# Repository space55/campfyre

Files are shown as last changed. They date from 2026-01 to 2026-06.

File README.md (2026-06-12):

# Campfyre

Campfyre is a rugged, battery-powered network‑in‑a‑box designed to keep you online when primary internet access fails. It can run off‑grid with Starlink, provide Ethernet, run a Raspberry Pi, and charge from a vehicle's 12V system. It's compact, durable, and built for travel and off‑grid use.

## Website

Visit the project website at **https://campfyre.org**.

## What Campfyre includes

- Starlink Mini for internet access and routing
- Ethernet switch for local connectivity
- Shared power bus (VBUS) feeding the switch, Starlink, and Raspberry Pi
- Power path controller that prioritizes external power while charging the battery
- 12V regulation with a secondary 5V supply for the Raspberry Pi
- Waterproof, radio‑transparent case for durability and signal quality

## Contributing

We welcome contributions. Please read the guidelines in [CONTRIBUTING.md](CONTRIBUTING.md), which include:

- Submitting changes via GitHub pull requests
- Following the project's community guidelines

For content edits, see the content guide in [site/README.md](site/README.md).

## License

See [LICENSE](LICENSE).

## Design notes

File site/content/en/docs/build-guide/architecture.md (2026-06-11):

---
title: Architecture
description: >
  See how Campfyre is put together.
weight: 3
---

Campfyre is designed around a few key subsystems. Green arrows in the diagrams
are for Ethernet, and red arrows are for power.

## Network

The network of Campfyre is designed to be centralized around a ruggedized
network switch, where a Starlink Mini, a Raspberry Pi, and the output jack are
all connected.

Network diagram for Campfyre

Starlink creates a WiFi hotspot, and connects via Ethernet to the network
switch. The switch then connects to the Raspberry Pi and the water-resistant
external ethernet jack.

## Power

Campfyre receives its power from an internal battery and an external 12V supply.

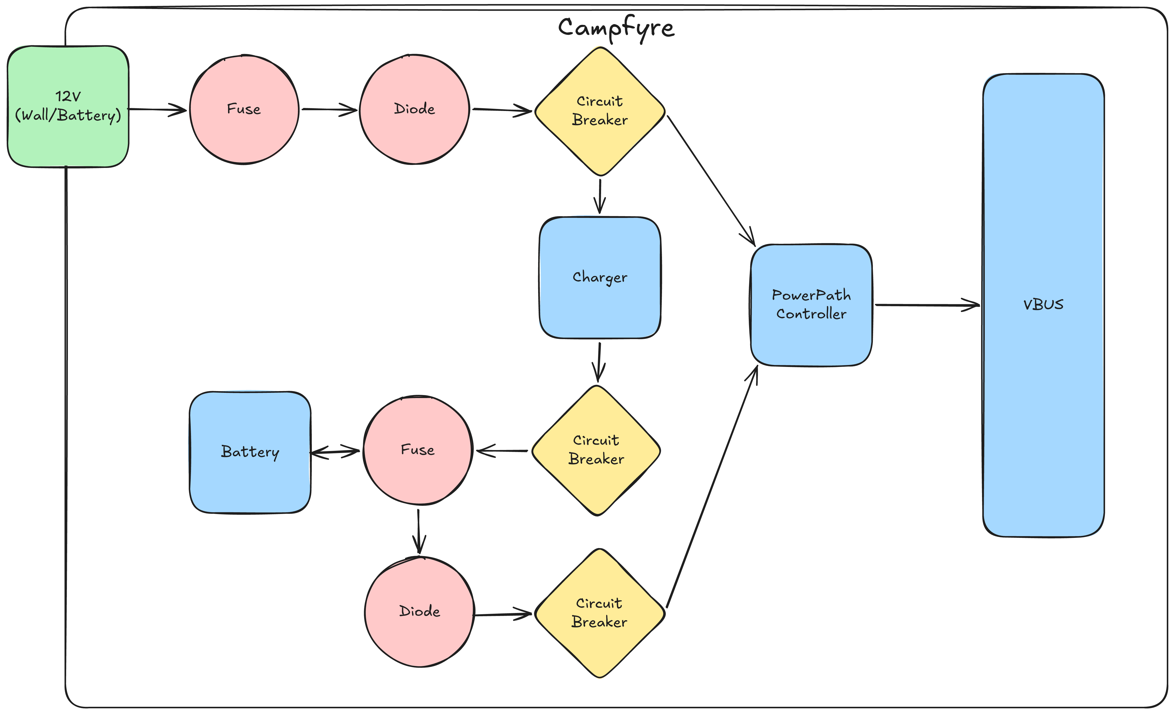
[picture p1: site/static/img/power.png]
Power diagram for Campfyre


### Components

- VIN
  - Main connector for external DC power. It should be water-resistant and
    support the power requirements needed for Campfyre, as discussed in
    [components](components/).
- Ideal Diode
  - This provides both reverse polarity protection externally, and prevents
    backfeeding of power from inside Campfyre to reach outside. In addition,
    this prevents VBUS from feeding back into the battery through the power path
    controller.
- Fuse
  - This is to provide overcurrent protection, preventing a short circuit from
    causing fires.
- Circuit Breaker
  - This is to turn on and off Campfyre internally, and provides additional
    protection against current spikes and short circuits.
- Charger
  - The charger is for maintaining the internal battery. It needs to support DC
    in at the voltages provided by VIN, and should prevent the battery from
    being overcharged.
- 12V Battery
  - The battery is a 4S LiFePO4 battery, which allows large numbers of
    charge/discharge cycles, and has a high capacity for its size. See its
    [components](components/#battery) page for more details.

## VBUS

VBUS is generated with a power path controller, switching automatically between
the two input sources (VIN and the battery). See its
[components](components/#power-path-controller) page for more details.

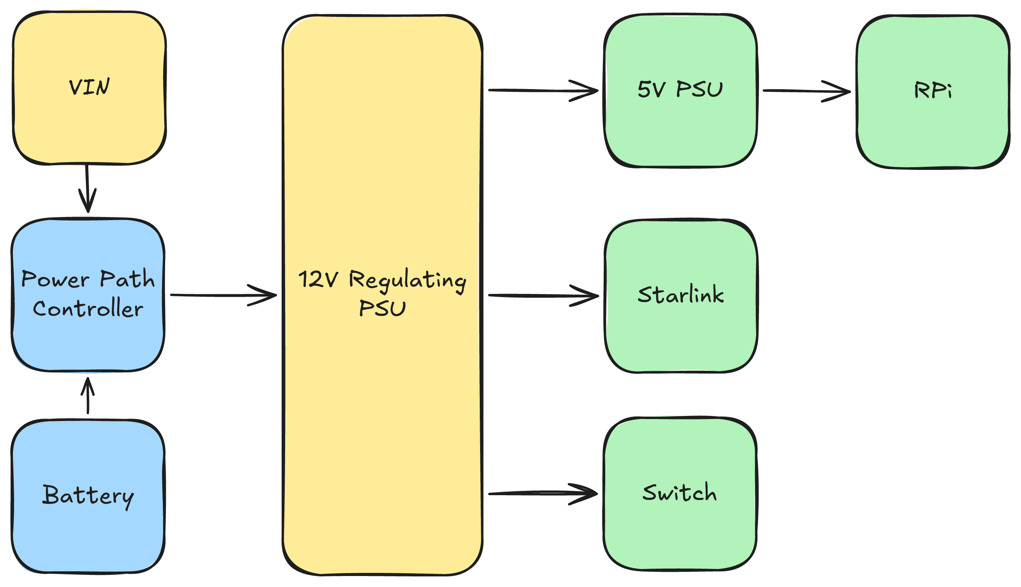
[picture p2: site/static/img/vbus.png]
VBUS for Campfyre


{{% alert title="WARNING" %}} Just because no circuit protection components are
shown in the above diagram doesn't mean they don't exist! Make sure to properly
install fuses, circuit breakers, and other components as detailed in the earlier
power architecture diagram. {{% /alert %}}

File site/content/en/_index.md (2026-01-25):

---
title: Campfyre
---

<style>
  .td-heading-self-link {
    display: none;
  }
  
  .td-cover-block {
    position: relative;
    overflow: hidden;
  }
  
  .td-cover-block h1,
  .td-cover-block .lead,
  .td-cover-block p {
    font-family: 'PixelDigivolve', monospace;
  }
  
  #smoke-canvas {
    position: absolute;
    top: 0;
    left: 0;
    width: 100%;
    height: 100%;
    z-index: 0;
    pointer-events: none;
    image-rendering: pixelated;
    image-rendering: crisp-edges;
  }
  
  .td-cover-block .td-overlay {
    position: relative;
    z-index: 1;
  }
</style>

{{< blocks/cover title="A portable, durable backup internet box" image_anchor="top" height="full" >}}

<canvas id="smoke-canvas"></canvas>

<div class="video-embed">
<iframe src="https://www.youtube.com/embed/kp6JwRd7_2c?si=8U0waY4wramVZBd4" title="YouTube video player" frameborder="0" allow="accelerometer; autoplay; clipboard-write; encrypted-media; gyroscope; picture-in-picture; web-share" referrerpolicy="strict-origin-when-cross-origin" allowfullscreen></iframe>
</div>

<a class="btn btn-lg btn-primary me-3 mb-4" href="/docs">
  Get Started
</a>
<a class="btn btn-lg btn-secondary me-3 mb-4" href="https://discord.gg/4y4aQuCQWj">
  Join the Community <i class="fab fa-discord ms-2 "></i>
</a>
<p class="lead mt-5">Backup internet for whenever you need it</p>

{{< blocks/link-down color="info" >}} {{< /blocks/cover >}}

<script>
(function() {
  const canvas = document.getElementById('smoke-canvas');
  if (!canvas) return;
  
  const ctx = canvas.getContext('2d');
  const PIXEL_SIZE = 6;
  
  let width, height, cols, rows;
  
  function resize() {
    const cover = canvas.closest('.td-cover-block');
    if (cover) {
      width = cover.offsetWidth;
      height = cover.offsetHeight;
    } else {
      width = window.innerWidth;
      height = window.innerHeight;
    }
    canvas.width = width;
    canvas.height = height;
    cols = Math.ceil(width / PIXEL_SIZE);
    rows = Math.ceil(height / PIXEL_SIZE);
  }
  
  resize();
  window.addEventListener('resize', resize);
  
  const particles = [];
  const MAX_PARTICLES = 150;
  
  const SMOKE_COLORS = [
    'rgba(60, 60, 70, 0.4)',
    'rgba(70, 70, 80, 0.35)',
    'rgba(80, 80, 90, 0.3)',
    'rgba(90, 90, 100, 0.25)',
    'rgba(100, 100, 110, 0.2)',
    'rgba(110, 110, 120, 0.15)',
    'rgba(120, 120, 130, 0.1)',
  ];
  
  class SmokeParticle {
    constructor() {
      this.reset();
    }
    
    reset() {
      this.x = Math.random() * cols;
      this.y = rows + Math.random() * 5;
      this.size = 1 + Math.floor(Math.random() * 3);
      this.vy = -(0.3 + Math.random() * 0.4);
      this.vx = (Math.random() - 0.5) * 0.3;
      this.drift = Math.random() * Math.PI * 2;
      this.driftSpeed = 0.02 + Math.random() * 0.02;
      this.opacity = 0.6 + Math.random() * 0.4;
      this.fadeRate = 0.002 + Math.random() * 0.002;
      this.colorIndex = 0;
    }
    
    update() {
      this.y += this.vy;
      this.drift += this.driftSpeed;
      this.x += this.vx + Math.sin(this.drift) * 0.15;
      
      const progress = 1 - (this.y / rows);
      this.colorIndex = Math.min(SMOKE_COLORS.length - 1, Math.floor(progress * SMOKE_COLORS.length));
      
      this.opacity -= this.fadeRate;
      
      if (this.y < -this.size || this.opacity <= 0) {
        this.reset();
      }
    }
    
    draw() {
      if (this.opacity <= 0) return;
      
      const px = Math.floor(this.x) * PIXEL_SIZE;
      const py = Math.floor(this.y) * PIXEL_SIZE;
      
      ctx.globalAlpha = this.opacity;
      ctx.fillStyle = SMOKE_COLORS[this.colorIndex];
      
      for (let i = 0; i < this.size; i++) {
        for (let j = 0; j < this.size; j++) {
          if (Math.random() > 0.3) {
            ctx.fillRect(
              px + i * PIXEL_SIZE,
              py + j * PIXEL_SIZE,
              PIXEL_SIZE,
              PIXEL_SIZE
            );
          }
        }
      }
      
      ctx.globalAlpha = 1;
    }
  }
  
  for (let i = 0; i < MAX_PARTICLES; i++) {
    const p = new SmokeParticle();
    p.y = Math.random() * rows;
    p.opacity = Math.random() * 0.6;
    particles.push(p);
  }
  
  function animate() {
    ctx.clearRect(0, 0, width, height);
    
    for (const particle of particles) {
      particle.update();
      particle.draw();
    }
    
    requestAnimationFrame(animate);
  }
  
  animate();
})();
</script>

{{% blocks/lead color="primary" %}}

After the Verizon outage in January of 2026, I wanted a backup internet
connection that I could put in a car or take with me if I needed. So I built
Campfyre - a battery-powered Starlink, Raspberry Pi, and network switch, in a
water-resistant case.

{{% /blocks/lead %}}

{{% blocks/section color="black" type="row" %}}

{{% blocks/feature icon="fa-hill-rockslide" title="Durable" %}}

Campfyre is built into a rock-solid and water-resistant carrying case, so you
can take it into the field, wherever you like.

{{% /blocks/feature %}}

{{% blocks/feature icon="fab fa-github" title="Open Source" url="https://github.com/space55/campfyre" %}}

Everything is open-source, including CAD, printable files, wiring diagrams, and
component listing. Found a better way to do something? Suggest a change!

{{% /blocks/feature %}}

{{% blocks/feature icon="fa-solid fa-earth-americas" title="Works anywhere" %}}

This works anywhere on Earth you can use Starlink. On a boat in the open ocean,
in a car driving through the wilderness, or on the roof of a building in a city.

{{% /blocks/feature %}}

{{% /blocks/section %}}

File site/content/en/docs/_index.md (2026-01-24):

---
title: Documentation
linkTitle: Docs
menu: { main: { weight: 20 } }
---

Welcome to the Campfyre docs. Campfyre is a rugged, battery-powered backup
internet box designed to keep you online when primary internet access fails. It
can run off-grid with Starlink, provide connectivity over Ethernet, run a
Raspberry Pi, and charge from a vehicle's 12V system.

## What Campfyre includes

- Starlink Mini for internet access and routing
- Ethernet switch for local connectivity
- Shared power bus (VBUS) feeding the switch, Starlink, and Raspberry Pi
- Power path controller that prioritizes external power while charging the
  battery
- 12V regulation with a secondary 5V supply for the Raspberry Pi
- Waterproof, radio-transparent case for durability and signal quality

## Why Campfyre

Campfyre is built for travel and off-grid use, providing an internet connection
wherever you need it. It provides reliable connectivity in a compact, rugged
form factor and is easy to assemble with basic tools.

## Get started

Start with the build guide [here](/docs/build-guide)

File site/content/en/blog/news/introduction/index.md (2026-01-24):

---
date: 2026-01-22
title: Introduction to Campfyre
linkTitle: Introduction to Campfyre
description: >
  The portable, rugged network-in-a-box that provides backup internet when you
  need it most.
author: Eamonn Nugent ([@space55](https://github.com/space55))
---

After the Verizon outage in Jan of 2026, I wanted a backup internet connection
that I could put in a car or take with me if I needed. So I built this.

Meet Campfyre. It's a battery powered and ruggedized network-in-a-box. Campfyre
can run completely off-grid with Starlink, providing internet access when you
need it most. Campfyre can also be charged from a car's 12V system, and is
sealed to prevent water damage. It's easy to build and requires only simple
tools to assemble. So how does it work? Let's get into it.

Network architecture for Campfyre

The main feature of Campfyre is centered around a Starlink Mini. The Starlink
Mini hosts a WiFi hotspot and has an Ethernet port, which is then connected to a
network switch. Because Starlink acts as a router, any device connected to the
switch can talk to the Internet, including a device connected to the external
Ethernet jack on Campfyre. In theory, an entire building could receive its
internet access through Campfyre (though speeds would be limited by how fast
Starlink can transmit and receive data).

Power diagram for Campfyre

Next, let's talk about how it's powered. Campfyre has two primary input
sources - external DC, and the internal LiFePO4 battery. It then has a shared
power bus, called VBUS, where the main power supplies connect to and draw from.
It feeds the Raspberry Pi (via a 5V power supply), the Starlink dish, and the
network switch. Campfyre can run for approximately two hours under heavy usage,
or up to four and a half hours maximum.

Power path diagram for Campfyre

To generate VBUS, external power and the battery connect to what is called a
power path controller that selects which input to use to supply the downstream
devices, giving priority to external power. This means that when Campfyre is
plugged in, it will charge the battery while keeping Starlink, the network
switch, and the Raspberry Pi online. The power path controller feeds into a 12V
regulating power supply. That then feeds directly to the Starlink and the
network switch, and into a secondary power supply for the Raspberry Pi.

break to image of Campfyre

The last important feature is the case in which everything is built. It's a
standard, off-the-shelf camera case with a waterproof seal and pressure
equalization valve. This means that Campfyre should be safe in the rain, though
submerging it in water is not recommended. The case is made of radio-transparent
polypropylene, so Starlink can communicate efficiently through the lid of the
case, as long as it has a clear view of the sky.

Campfyre is a ruggedized network-in-a-box for camping, traveling, or just a
backup internet connection if your home internet goes out. In the next video,
you'll learn how to build your own Campfyre, where to get the parts, and what to
expect from the process.

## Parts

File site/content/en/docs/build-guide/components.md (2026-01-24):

---
title: Components
description: >
  The basic components that make up Campfyre.
weight: 2
---

These are the basic components that Campfyre utilizes. Each component will have
a brief description of why it was selected, and any specific requirements for
choosing a replacement. Note that only the listed components have shown to work,
and untested replacements are not guaranteed to operate (or fit) properly.

[Google Sheet link](https://docs.google.com/spreadsheets/d/19ZAjStZ-obC8wSNhDvEN2Lx9rUpaaM5_dhgU9AE4784/edit?gid=0#gid=0)
to primary component listing.

## Notes before starting

Campfyre has been designed to support 15A of load on downstream devices within
the case. Starlink takes up to 5A input, and a Raspberry Pi 5 can require up to
5A. It is recommended to use the Starlink without snow melt mode. It is also
recommended to use a Raspberry Pi 4 Model B, as Pi 5s are power-hungry and
output a lot of heat.

## Starlink Mini

Campfyre has been designed around the use of a Starlink Mini with a Roam plan.
Starlink _must_ be activated with in-motion use enabled (Roam plan), as the goal
of Campfyre is to provide internet service without a dedicated location
selected.

Make sure you turn off snow melt mode on the Starlink, otherwise it will heat up
internally and could cause damage in the sealed environment within the case.

## Power Supply & Management

These are the bread and butter of the internal architecture of Campfyre. Each
one

### 12V VBUS Power Supply

This is the main VBUS power supply that connects between the power path
controller and the downstream devices, such as the Starlink Mini and the network
switch.

The VBUS supply must accept 8-15V DC, and regulate it to an even 12V. This is to
smooth out the power from the battery, vehicle alternator/battery, or other
sources that may not deliver "clean" power.

#### Requirements

- 8-15V DC in
- 12V @ 8A+ out

### 5V Power Supply

This is to provide power to the Raspberry Pi. It should accept 12V DC in, and
output 5.1V at 3A or more. Any 5V DC-DC power supply that fits your case should
work, but the one selected has been validated to work well.

#### Requirements

- 12V DC in
- 5.1V @ 3A+ out

### Power Path Controller

This is the device that switches between external DC in (VIN) and the battery to
power downstream devices. It sits between the battery, VIN, and the primary VBUS
supply. It is not an easy part to find replacements for. It must be able to
switch between VIN and battery instantaneously, and must be solid-state. Relays
are too slow for power to transition smoothly, and could cut out power to
Starlink or to the Raspberry Pi.

#### Requirements

- 8-15V DC in for VIN
- 8-15V DC in for battery
- 8-15V DC out for downstream devices
- Automated cutover between external DC and battery
- Handle at least 8A of current, but recommended to have a safety factor of at
  least 2

### Battery

The battery is one of the most important parts of the device. It must be able to
supply at least 8A of current, and be of _the same chemistry_ as the charger
supports.

{{% alert title="WARNING" %}} Batteries are dangerous. Large capacity ones
especially so. For Campfyre to remain safe, you _must_ purchase 12V LiFePO4
batteries. LiPo/Li-Ion batteries are not compatible, and sealed lead-acid (SLA)
batteries are also not compatible. Using a LiFePO4 charger with the wrong type
of batteries can result in an explosion. Do not charge a LiFePO4 battery at
temperatures below freezing. {{% /alert %}}

#### Requirements

- 8A+ discharge current (ideally >10A)
- 12V (4S) LiFePO4 battery

### Battery Charger

The battery charger must accept 8-15V DC in and boost the voltage to standard
charging voltages for the battery you've chosen. In addition, it should support
the chemistry of the battery selected.

DC-DC battery chargers are fairly rare, and so the one selected for Campfyre has
already been validated to work with the selected battery and voltage input.

#### Requirements

- 8-15V DC in
- 12V (4S) LiFePO4 battery support

## Protection

### Circuit Breakers

The circuit breakers are used to turn on and off the power inside Campfyre, and
prevent sudden spikes from causing sparks, fires, or melting wires. The circuit
breakers should be rated for 15A, and support switching under load.

#### Requirements

- 24V+ DC rating
- 15A capacity rating
- B curve or better
- Switch under load

### Fuses

25A fuses should be used to protect Campfyre, and placed on both the battery
positive lead and VIN positive lead. MIDI fuses are used for ease of
installation, and ease of sourcing. It is recommended against using automotive
blade fuses.

#### Requirements

- 24V+ DC rating
- 25A DC rating

### External Connectors

Campfyre uses
[Cnlinko](https://www.amazon.com/stores/page/F13776C8-E8BD-4309-9AB0-ED23CD712609)
connectors for VIN and the Ethernet jack, due to their waterproofing. Any
connector that is capable of handling 15A of current at 12V DC, though, should
be usable.

#### Requirements

- 15A DC rating
- 24V+ DC rating
- 2 or 3 pin for power
- RJ45 for Ethernet

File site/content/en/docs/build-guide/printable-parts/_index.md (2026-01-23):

---
title: Printable Parts
description: Parts to print for your Campfyre
weight: 10
---

These are all the parts you need to print to build your own Campfyre.

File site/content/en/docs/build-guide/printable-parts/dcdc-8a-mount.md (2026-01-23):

---
title: DCDC-8A Mount
description: >
  The DCDC-8A Mount is the mount that holds the DCDC-8A in the case, allowing
  for it to be removed by unscrewing it rather than having it permanently
  affixed directly into the case.
---

<script type="importmap">
  {
    "imports": {
      "three": "https://cdn.jsdelivr.net/npm/three@0.160.0/build/three.module.js"
    }
  }
</script>

<script type="module">
  import { init3DModelViewer } from "/js/stlviewer.js";
  init3DModelViewer({
    stlUrl: "https://raw.githubusercontent.com/space55/campfyre/refs/heads/main/cad/DCDC-8A%20Mount.stl"
  });
</script>

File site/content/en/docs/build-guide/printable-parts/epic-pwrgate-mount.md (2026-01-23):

---
title: Epic PWRGate Mount
description: >
  The Epic PWRGate is the power path controller which selects the power source
  to use for supplying the rest of Campfyre.
---

<script type="importmap">
  {
    "imports": {
      "three": "https://cdn.jsdelivr.net/npm/three@0.160.0/build/three.module.js"
    }
  }
</script>

<script type="module">
  import { init3DModelViewer } from "/js/stlviewer.js";
  init3DModelViewer({
    stlUrl: "https://raw.githubusercontent.com/space55/campfyre/refs/heads/main/cad/Epic%20PWRGate%20Mount.stl"
  });
</script>

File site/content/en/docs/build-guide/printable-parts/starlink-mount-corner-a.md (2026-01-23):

---
title: Starlink Mount Corner A
description: >
  This is what screws into the Starlink Mount to hold the Starlink Mini in
  place. Print two of these for Campfyre.
---

<script type="importmap">
  {
    "imports": {
      "three": "https://cdn.jsdelivr.net/npm/three@0.160.0/build/three.module.js"
    }
  }
</script>

<script type="module">
  import { init3DModelViewer } from "/js/stlviewer.js";
  init3DModelViewer({
    stlUrl: "https://raw.githubusercontent.com/space55/campfyre/refs/heads/main/cad/Starlink%20Mount%20Corner%20A.stl"
  });
</script>

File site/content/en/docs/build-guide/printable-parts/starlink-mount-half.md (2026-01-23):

---
title: Starlink Mount Half
description: >
  This is the base that attaches to the case, to which the Starlink is then
  attached. Print two of these for Campfyre.
---

<script type="importmap">
  {
    "imports": {
      "three": "https://cdn.jsdelivr.net/npm/three@0.160.0/build/three.module.js"
    }
  }
</script>

<script type="module">
  import { init3DModelViewer } from "/js/stlviewer.js";
  init3DModelViewer({
    stlUrl: "https://raw.githubusercontent.com/space55/campfyre/refs/heads/main/cad/Starlink%20Mount%20Half.stl"
  });
</script>

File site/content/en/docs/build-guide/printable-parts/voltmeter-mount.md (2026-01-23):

---
title: Voltmeter Mount
description: >
  This attaches the voltmeter (and associated pushbutton) to the side of the
  case, so you can check the battery voltage.
---

<script type="importmap">
  {
    "imports": {
      "three": "https://cdn.jsdelivr.net/npm/three@0.160.0/build/three.module.js"
    }
  }
</script>

<script type="module">
  import { init3DModelViewer } from "/js/stlviewer.js";
  init3DModelViewer({
    stlUrl: "https://raw.githubusercontent.com/space55/campfyre/refs/heads/main/cad/Voltmeter%20Mount.stl"
  });
</script>

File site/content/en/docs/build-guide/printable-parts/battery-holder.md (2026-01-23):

---
title: Battery Holder
description:
  A 150x65mm battery holder that uses hook-and-loop fasteners to hold everything
  in place.
weight: 1
---

<script type="module" src="https://ajax.googleapis.com/ajax/libs/model-viewer/4.0.0/model-viewer.min.js"></script>

<model-viewer alt="A 150x65mm battery holder that uses hook-and-loop fasteners to hold everything
  in place." src="https://raw.githubusercontent.com/space55/campfyre/refs/heads/main/cad/150x65mm%20Battery%20Holder.step" shadow-intensity="1" camera-controls touch-action="pan-y"></model-viewer>

This is the main battery holder. It is designed to fit 150x65mm batteries, with
a hook-and-loop (Velcro®) fastener strip to keep everything in place.

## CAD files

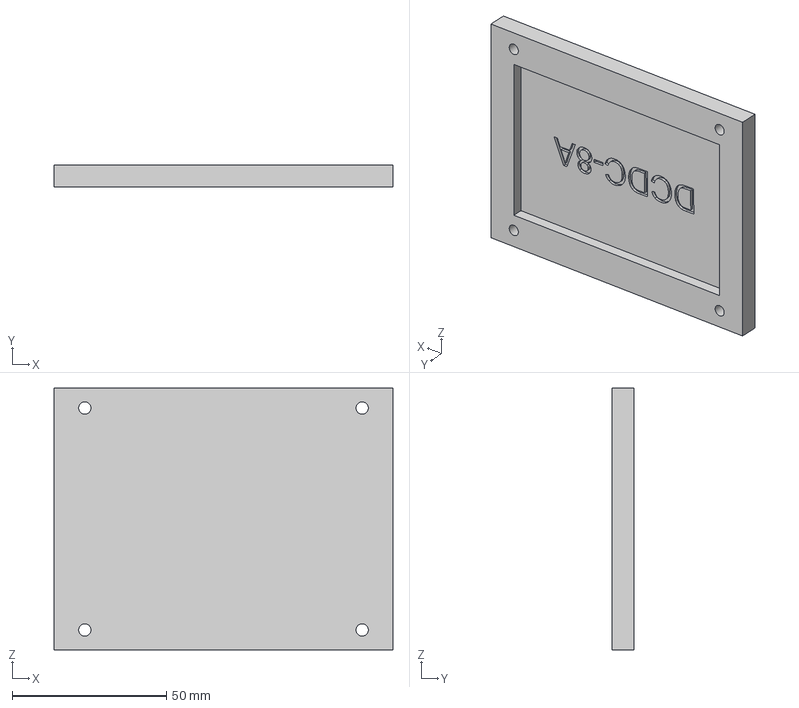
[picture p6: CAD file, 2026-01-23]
cad/DCDC-8A Mount.step
110.0 x 7.00 x 85.0 mm

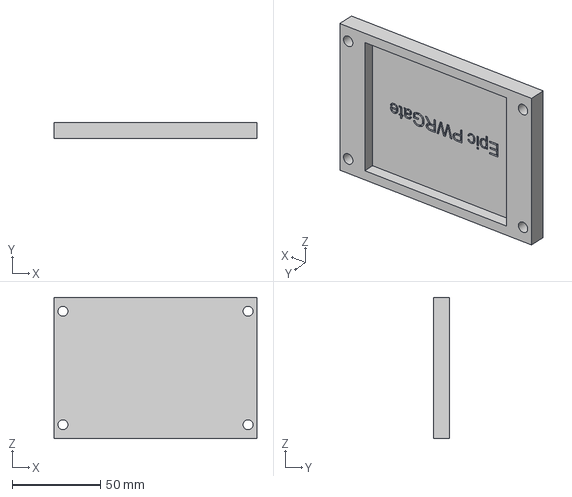
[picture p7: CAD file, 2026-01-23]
cad/Epic PWRGate Mount.step
115.0 x 9.00 x 80.0 mm

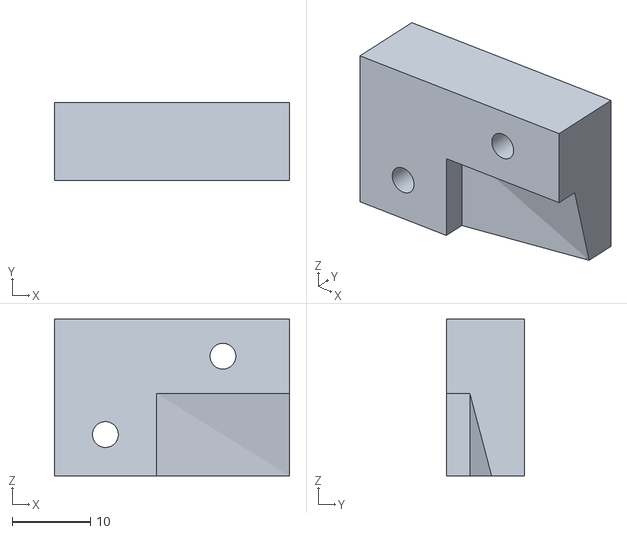
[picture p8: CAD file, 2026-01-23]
cad/Starlink Mount Corner B.stl
30.0 x 10.0 x 20.0

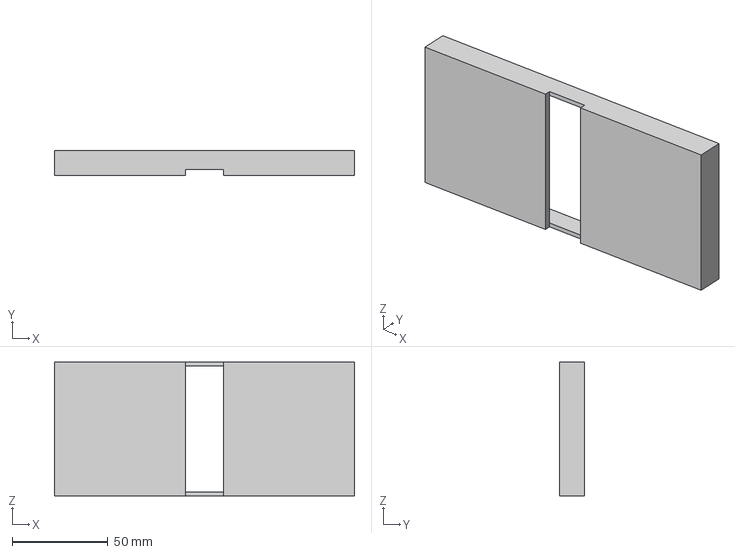
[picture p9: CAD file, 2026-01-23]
cad/150x65mm Battery Holder.step
157.0 x 13.0 x 70.0 mm

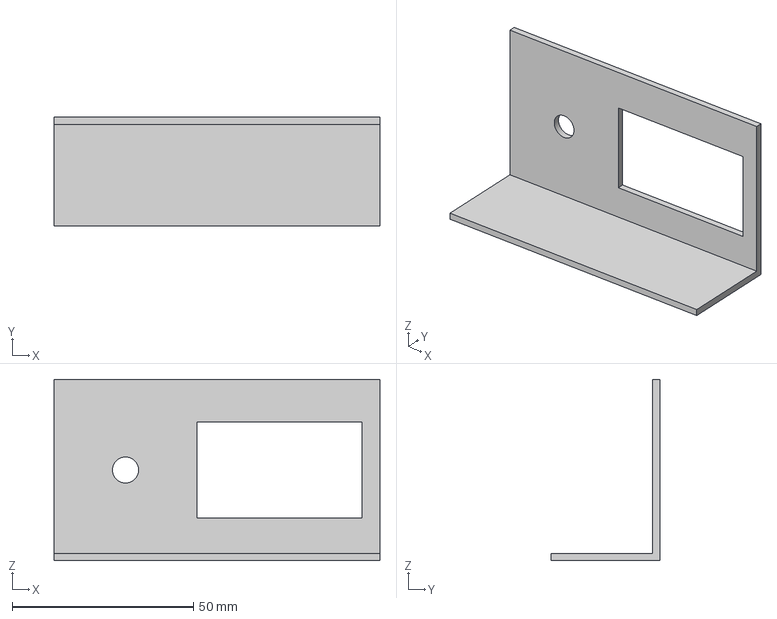
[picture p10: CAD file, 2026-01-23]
cad/Voltmeter Mount.step
90.0 x 30.0 x 50.0 mm

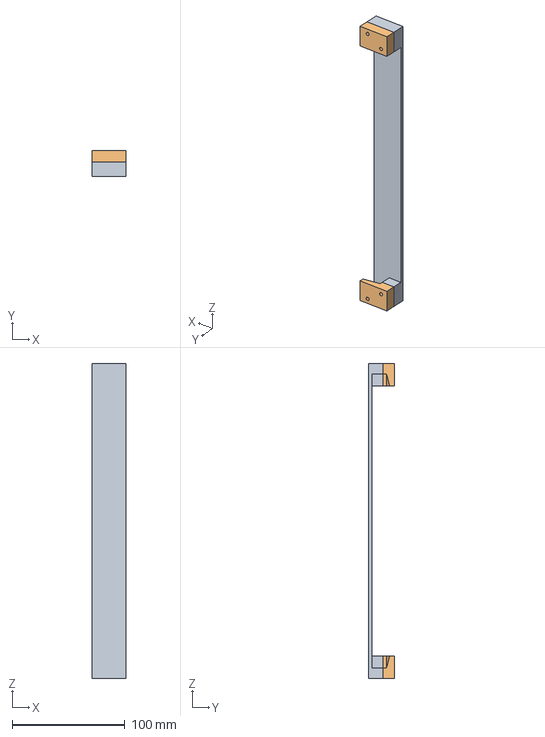
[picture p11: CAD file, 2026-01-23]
cad/Starlink Mount Half.step
30.0 x 23.0 x 278.9 mm

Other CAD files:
cad/Starlink Mount Corner A.stl
cad/150x65mm Battery Holder.stl
cad/DCDC-8A Mount.stl
cad/Epic PWRGate Mount.stl
cad/Starlink Mount Half.stl
cad/Voltmeter Mount.stl

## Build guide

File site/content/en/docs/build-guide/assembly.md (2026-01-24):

---
title: Assembly
description: >
  Begin the adventure of assembling your Campfyre.
weight: 4
---

# Assembly Instructions

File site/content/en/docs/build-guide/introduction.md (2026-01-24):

---
title: Introduction
description: >
  Learn the basics for how Campfyre works, what you need to know, and the
  prerequisites for making your own.
weight: 1
---

## Tools

To get started building your own Campfyre, you'll need the following tools.

1. 3D Printer
1. Soldering iron
1. Power drill
1. Wire cutter
1. Screwdriver set
1. Ring terminal crimp tool
1. Lighter/heat source (for heat shrink tubing)
1. 120-160 grit sand paper
1. Scissors

## Consumables

A few consumables will be needed to build Campfyre.

1. 12 AWG wire (red and black)
1. M3 screws (assorted)
1. M3 heat-set inserts
1. M4 screws (assorted)
1. M4 heat-set inserts
1. 3M Low Surface Energy VHB Tape (3M LSE-060WF)
1. Ethernet cables
1. 5.5x2.5mm DC plug
1. M3 and M5 yellow ring terminals for 12 AWG wire

{{% alert title="WARNING" %}} Purchasing specifically **3M LSE VHB** tape is
_absolutely essential_. No, foam mounting tape will not work. You _must_
purchase [exactly this](https://www.mcmaster.com/76675A52/) tape for Campfyre to
work. It's possible you will use an entire 15ft roll of 1/2-in tape to build
Campfyre. {{% /alert %}}

## Components

Components are discussed further on their
[dedicated page](/docs/build-guide/components/).

## Printable Parts

### [150x65mm Battery Holder](/docs/build-guide/printable-parts/battery-holder)

{{< subpage-description "/docs/build-guide/printable-parts/battery-holder" >}}

### [DCDC-8A Mount](/docs/build-guide/printable-parts/dcdc-8a-mount)

{{< subpage-description "/docs/build-guide/printable-parts/dcdc-8a-mount" >}}

### [Epic PWRGate Mount](/docs/build-guide/printable-parts/epic-pwrgate-mount)

{{< subpage-description "/docs/build-guide/printable-parts/epic-pwrgate-mount" >}}

### [Starlink Mount Corner A](/docs/build-guide/printable-parts/starlink-mount-corner-a)

{{< subpage-description "/docs/build-guide/printable-parts/starlink-mount-corner-a" >}}

### [Starlink Mount Corner B](/docs/build-guide/printable-parts/starlink-mount-corner-b)

{{< subpage-description "/docs/build-guide/printable-parts/starlink-mount-corner-b" >}}

### [Starlink Mount Half](/docs/build-guide/printable-parts/starlink-mount-half)

{{< subpage-description "/docs/build-guide/printable-parts/starlink-mount-half" >}}

### [Voltmeter Mount](/docs/build-guide/printable-parts/voltmeter-mount)

{{< subpage-description "/docs/build-guide/printable-parts/voltmeter-mount" >}}

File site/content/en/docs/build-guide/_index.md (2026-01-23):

---
title: Build Guide
description: Build your own Campfyre
weight: 1
---

Build Guide Details

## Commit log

2026-01-23 Add CAD
    [150x65mm Battery Holder.step, 150x65mm Battery Holder.stl, DCDC-8A Mount.step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]
2026-01-23 Add back STL Viewer
2026-06-11 Main power diagram
2026-11-08 Add wiring diagram
